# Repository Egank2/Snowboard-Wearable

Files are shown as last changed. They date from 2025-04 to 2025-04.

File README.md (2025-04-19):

# 🏂 Snowboard Wearable – IoT-Based Ride Tracker

Welcome to the Snowboard Wearable project repository! This system is designed to help snowboarders visualize, analyze, and improve their performance using a wearable IoT device and a companion mobile application. It combines real-time sensor data, Bluetooth connectivity, trick recognition, and a gamified mobile UI for a next-generation snowboarding experience.

---

## 📱 Mobile App Features

- 🌤 **Weather & Conditions Dashboard** (Live resort data)
- 🏔 **Popular Resorts** listing with status
- 🔋 **Equipment Status Monitor** (Device, goggles, bindings)
- 🏆 **Leaderboards** (Daily, Weekly, Monthly, All-Time)
- 📊 **Trick Analytics** (Top speed, airtime, spins)
- 🕹 **3D Playback** of runs with XP scoring
- 👤 **User Profile & Stats** (XP, badges, levels)

Built using **Flutter**, supports Android 10+ and iOS 14+.

---

## ⚙️ Hardware Features

- 🎯 **ESP32-WROVER Module** for BLE and onboard control
- 🧭 **BNO086 IMU Sensor** for 9-axis motion tracking
- 🔌 **USB-C Charging** with Li-ion battery management
- 📉 **Low-Dropout Regulator (LDO)** for power efficiency
- 🧩 Designed and simulated in **KiCad 7.0**

---

## 🧪 Current Development Status

| Component | Status |
|---|---|
| Mobile UI | ✅ In Progress |
| ESP32 Firmware | ✅ Completed |
| IMU Integration | ✅ Completed |
| Trick Recognition ML | ✅ In Progress |
| Cloud Sync & Storage | 🔄 Planned |
| Hardware Prototype | ✅ Assembled |
| Full Integration | ❌ Not Completed |

---

## 🔧 Getting Started

### 📱 Mobile App (Swift)

### ⚡ Firmware (ESP32)

- Board: `ESP32-WROVER-E`
- Upload via USB using PlatformIO or Arduino IDE
- Ensure I²C is connected to the IMU (BNO086) with proper pull-ups

## 🧑‍💻 Team 06 — WIT COMP4960

- Emerson Herrera  
- Kenneth Egan
- Aakash Mukherjee 
- David Kennet  
- Victor Lomba  
Instructor: Dr. Joshua Gyllinsky

---

## 📘 Documentation

- [📄 SRS – Software Requirements Spec](Documents/SRS(Version%201.5).pdf)
- [📄 SDD – Software Design Document](Documents/SDD(Version%201.4).pdf)

---

## 🤝 Contributions

Pull requests are welcome! For major changes, please open an issue first to discuss what you'd like to change.  
Please follow our [Code of Conduct](docs/CODE_OF_CONDUCT.md).

---

## 📜 License

This project is intended for academic and research use only.
All rights reserved. Unauthorized use, reproduction, or distribution is prohibited.

---

## 🏔️ Let's Ride.

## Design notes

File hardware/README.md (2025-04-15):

# Hardware
## Overview
### electrical
KiCad9 project files. Contains PCB layout and schematic.
### models
3D CAD models of the housing. Contains the cover and bottom housing models.
### software
Software that runs in the microcontroller on the PCB.

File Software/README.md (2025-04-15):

# Software
## Overview
### max_velocity.py
Script that finds the maximum velocity of a run.
### plotter.py
Connects to a snowboard device through Bluetooth. Visualizes in 3D and logs to a file.
### snowboard_wearable.py
Detects snowboarding techniques and plots the result.
### test_bt.py
Bluetooth test script.
### trick_recognition.py
Detects tricks in a run.
## Setup
### Install python requirements
```
$ pip install -r requirements.txt
```
## Usage
### Running any of the scripts
```
$ python [script name]
```

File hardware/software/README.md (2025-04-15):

# software
## Overview
### snowtrack
ESP-IDF project that was supposed to run on the ESP32. After having issues with the newer v5.5.0 I2C driver along with time constraints due to ski resort availability, we decided to abandon this project.

The reason for the issues stems from the BNO08x requiring that the host device has SCL clock stretching enabled. However, the ESP32 I2C driver does not have SCL stretch capability. This was realized after committing to using a ESP32-WROVER and I2C. If I were to do this again I would redesign the board to use SPI instead.
### snowtrack-proto
Simple arduino program that sends the current rotation of the BNO086 to a host through Bluetooth.

This is what was used to record all of the snowboarding runs.

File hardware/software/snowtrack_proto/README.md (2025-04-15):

# snowtrack_proto
## Build & Flash
1. Install esp32 in the Arduino IDE board manager.
2. Select ESP32 Wrover Module in the board selection.
3. Have ESP32 connected and press Upload.
4. The device should show up as 'SnowTrack'

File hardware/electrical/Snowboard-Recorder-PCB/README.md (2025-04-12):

# Snowboard-Recorder-PCB
Snowboard performance tracking PCB.

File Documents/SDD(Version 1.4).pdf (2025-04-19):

# Snowboarding Wearable SDD

WIT COMP4960 Group 06
Version 1.4
Instructor: Dr. Joshua Gyllinsky https://github.com/Egank2/Snowboard-Wearable.git

Emerson Herrera, Aakash Mukherjee, Kenneth Egan, David Kennet, Victor Lomba

April 14, 2025

## Contents

1 Introduction | 2
2 System Requirements | 3
3 System Architecture | 4
4 System Design | 6
5 Hardware Architecture & Electrical Design | 9
6 Mobile Application UI Design | 11
7 Test Plan | 15
8 References | 15
9 Conclusion & Status Summary | 15

## Revision History

Date | Version | Description | Author(s)
Mar 19, 2025 | 1 | First Draft | Group 6
Apr 14, 2025 | 2 | Final Draft | Group 6

## 1 Introduction

### 1.1 Document Purpose

This document provides a comprehensive software design for the Snowboarding Wearable project. It details the architecture, system components, and design decisions that satisfy the system requirements defined in the SRS. The purpose is to serve as a guide for implementation and future maintenance while ensuring alignment with user needs and technical constraints.

### 1.2 Product Overview

The Snowboarding Wearable is a wearable IoT device for snowboarders that attaches to the board and connects to a phone via Bluetooth. It collects data from sensors like a gyroscope, accelerometer, GPS, and altimeter, providing post-ride analysis such as speed, airtime, technique analysis, and trick recognition. It can analyze snowboard-specific dynamics like carving angles, board flex, and snow conditions. Ride visualization, performance grading, and tips to help riders improve and tailor their experience to different terrains, making it an essential tool for snowboarders of all levels.

1.2.1 Problem Statement: Snowboarders lack a dedicated tool for analyzing ride performance and improving techniques.

1.2.2 Proposed Solution: A wearable IoT device coupled with a mobile app that provides real-time feedback and post-ride analytics.

1.2.3 Novelty: Focus on snowboard-specific dynamics (carving angles, edge angles, posture) with advanced trick recognition and performance grading.

### 1.3 Product Functionality

1.3.1 Real-Time Data Collection: Continuously capture sensor data (gyroscope, accelerometer, GPS, altimeter).

1.3.2 Trick Recognition: Identify snowboard tricks using predefined movement signatures.

1.3.3 Performance Grading: Analyze parameters such as carving efficiency, airtime, and landing stability.

1.3.4 Data Visualization: Present 3D ride visualizations and detailed performance graphs on the mobile app.

1.3.5 Historical Data Analytics: Store ride history for long-term progress tracking.

1.3.6 Wireless Communication: Ensure seamless Bluetooth connectivity between the wearable and mobile app.

### 1.4 Definitions

1.4.1 IoT: Internet of Things

1.4.2 BLE: Bluetooth Low Energy

1.4.3 GPS: Global Positioning System

1.4.4 ESP32: A low-power microcontroller with integrated Bluetooth/Wi-Fi

1.4.5 IMU: Inertial Measurement Unit (e.g BNO086)

### 1.5 Acronyms and Abbreviations

1.5.1 SDD: Software Design Document

1.5.2 SRS: Software Requirements Specification

1.5.3 UI: User Interface

1.5.4 API: Application Programming Interface

1.5.5 MVC: Model-View-Controller

1.5.6 PCB: Printed Circuit Board

## 2 System Requirements

### 2.1 Functional Requirements

Based on the SRS and architectural design, the system must:

2.1.1 Bluetooth Connectivity: Enable a stable Bluetooth connection between the wearable device and the mobile app.

2.1.2 Sensor Data Collection: Gather data from gyroscope, accelerometer, GPS, and altimeter sensors at a sampling rate of 200Hz.

2.1.3 Trick Recognition: Process movement data using machine learning algorithms to identify and score tricks.

2.1.4 Real-Time Performance Grading: Provide immediate feedback on ride metrics such as carving angles and landing stability.

2.1.5 User Interface for Data Visualization: Display real-time and historical ride data through an intuitive mobile app interface.

2.1.6 Cloud Integration: Support data storage and long-term trend analysis.

### 2.2 Non-functional Requirements

2.2.1 Performance:

- Data transmission latency ≤ 50ms.
- Sensor sampling rate of 200Hz.

2.2.2 Reliability: Device must function in extreme cold (as low as –20°C) and snowy conditions.

2.2.3 Battery Life: Minimum operational time of 4–8 hours per charge.

2.2.4 Packaging: Compact and durable design, ensuring minimal interference with rider movement.

2.2.5 Security: Encrypted Bluetooth data transmission and secure data storage.

2.2.6 Platform Compatibility: Mobile app to support Android 10+ and iOS 14+.

## 3 System Architecture

### 3.1 Overall Architecture

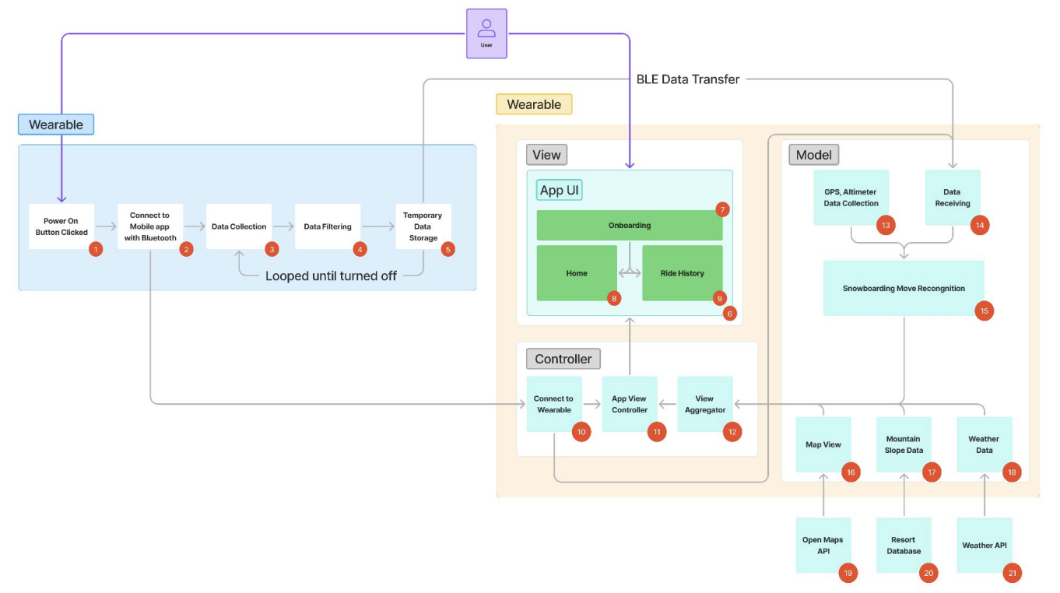
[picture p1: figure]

The system follows a combination of a Client-Server model, an MVC and a pipe and filter consisting of two primary components:

IoT Wearable (Client): Utilizes a Pipe & Filter pattern to collect and pre-process sensor data. The core hardware includes an ESP32 for Bluetooth communication and sensors (e.g., BNO086) for motion tracking.

Mobile App (Server): Implements a Model-View-Controller (MVC) design to ensure a clear separation between the user interface, data processing (using TensorFlow Lite for trick recognition), and control logic. The app manages data visualization, performance grading, and cloud integration.

### 3.2 Components Mapping

The functional and non-functional requirements are mapped to specific system components as follows:

Functional Requirements Mapping

3.2.1.1 Bluetooth Connectivity: (2, 10) Handled by the ESP32 and Flutter Blue library on the mobile app.

3.2.1.2 Sensor Data Collection: (1, 2, 3, 4, 5, 13) Managed by the wearable’s sensor module and data filtering algorithms.

3.2.1.3 Trick Recognition: (13, 14, 15) Executed on the mobile app using TensorFlow Lite along with predefined movement signatures.

3.2.1.4 Performance Grading: (13, 14, 15) Integrated within the mobile app’s analytics module.

3.2.1.5 Data Visualization: (15, 17, 12, 11, 6) Provided by the mobile app’s UI components, including 3D ride visualization.

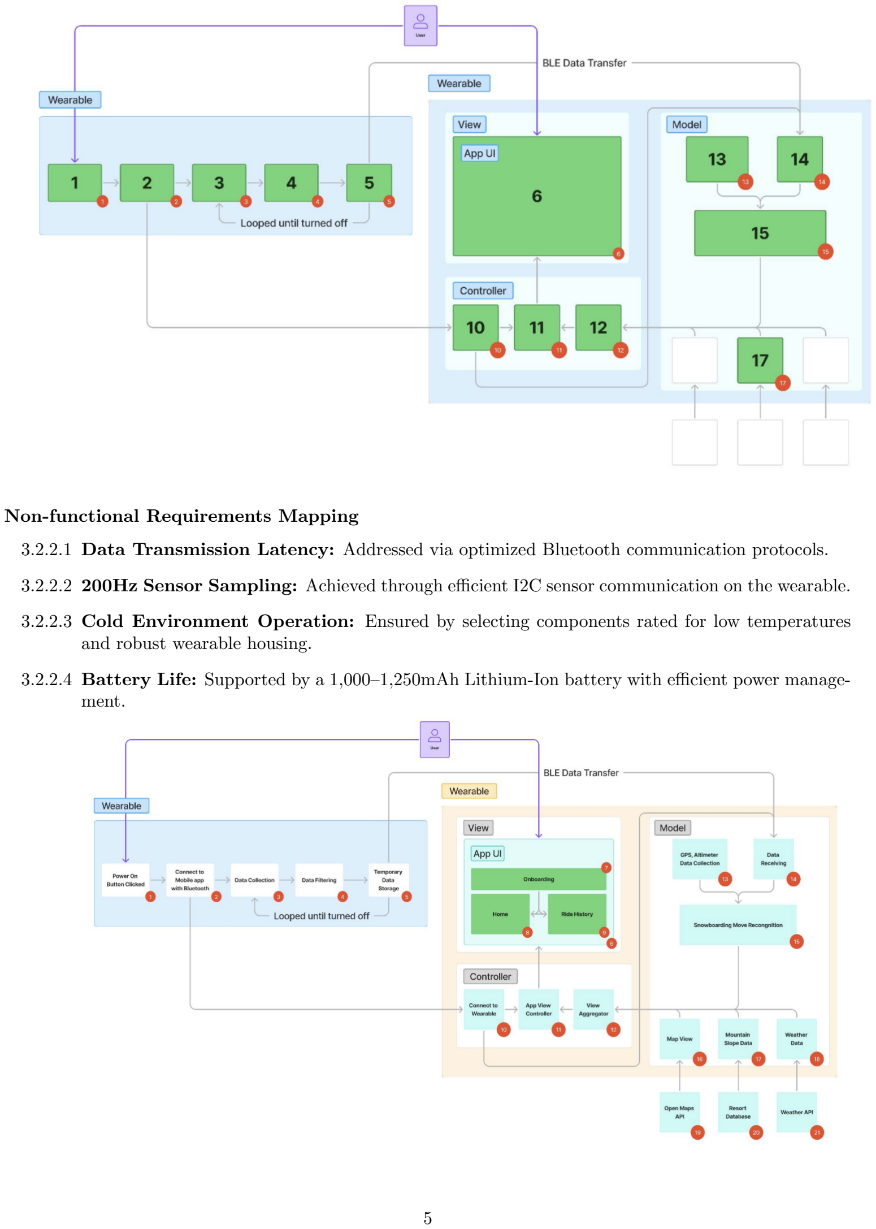
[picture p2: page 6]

Non-functional Requirements Mapping

3.2.2.1 Data Transmission Latency: Addressed via optimized Bluetooth communication protocols.

3.2.2.2 200Hz Sensor Sampling: Achieved through efficient I2C sensor communication on the wearable.

3.2.2.3 Cold Environment Operation: Ensured by selecting components rated for low temperatures and robust wearable housing.

3.2.2.4 Battery Life: Supported by a 1,000–1,250mAh Lithium-Ion battery with efficient power management.

### 3.3 Technology Stack Selection

3.3.1 Mobile App:

3.3.1.1 Flutter: For cross-platform UI development.
3.3.1.2 Flutter Blue: To manage Bluetooth Low Energy (BLE) communication.

3.3.1.3 TensorFlow Lite: For executing on-device machine learning models for trick recognition.

3.3.2 APIs:

3.3.2.1 Open Maps API: To fetch slope and mapping data.

3.3.2.2 Weather API: To deliver real-time snow and weather conditions.

3.3.3 Wearable Hardware:

3.3.3.1 ESP32: For Bluetooth and onboard processing.

3.3.3.2 Sensors: BNO086 for motion and orientation data.

3.3.3.3 Battery Pack: 3.7V, 1,000–1,250mAh Lithium-Ion battery ensuring power efficiency in cold climates.
3.3.3.4 Enclosure: IP67/IP68-rated housing for durability.

## 4 System Design

### 4.1 User Interface (UI)

The mobile app UI is designed with the following screens:

– Splash Screen: Displays the app logo for 3–5 seconds upon launch.

– Onboarding Screen: Guides first-time users through device pairing and setup.

– Home Screen:

- Real-time 3D visualization of snowboard movements.
- Map view displaying current ride path and GPS tracking.
- Performance scoring and feedback section.

– History Log Page:

- List of previous rides with metadata (date, time, score, etc.).
- Detailed view for individual ride analytics with graphs and 3D replay.

– Navigation Bar: Persistent access to key sections of the app.

### 4.2 Use Case Diagrams and Tables

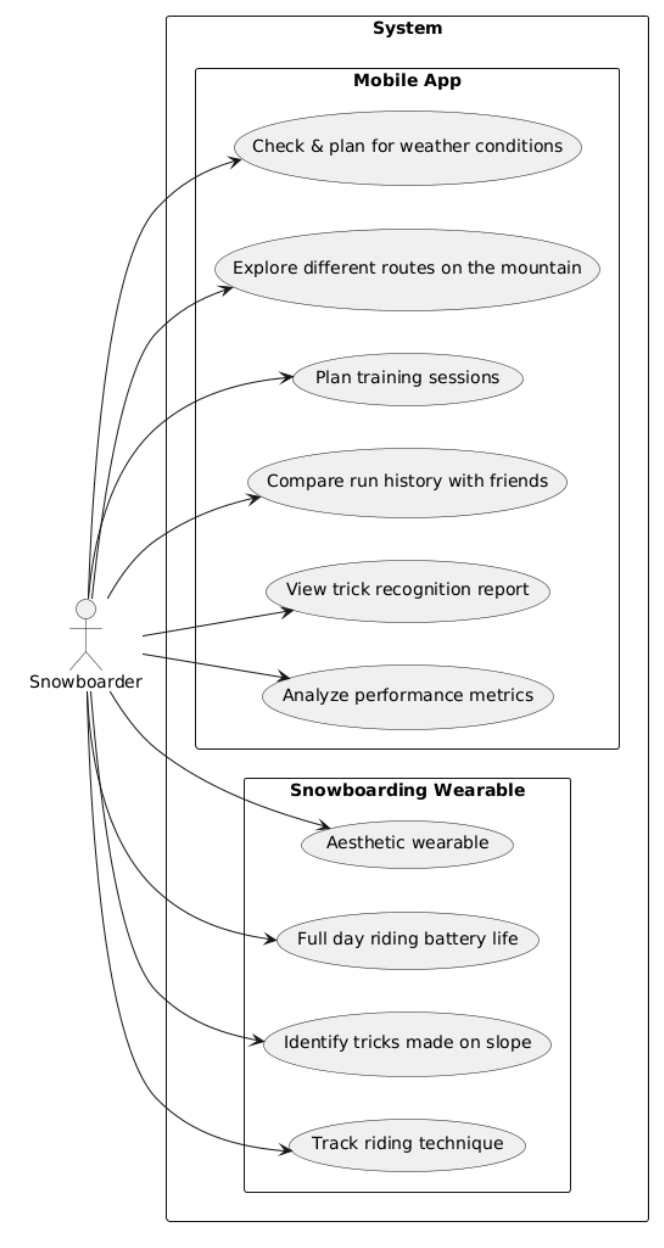
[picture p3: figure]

– Device Pairing:

- Actors: User, Wearable Device, Mobile App.
- Description: The user initiates Bluetooth pairing; the mobile app establishes a connection and confirms device readiness.

– Real-Time Data Visualization:

- Actors: User, Mobile App.
- Description: Sensor data is received and processed, then visualized on the home screen.

– Trick Recognition and Feedback:

- Actors: User, Mobile App.
- Description: The mobile app analyzes sensor inputs, recognizes tricks, and provides performance grading.

Detailed use case tables are maintained in the project repository.

### 4.3 Class Diagram

The class diagram includes (but is not limited to) the following classes:

– MobileApp:

- Attributes: userProfile, rideHistory, currentSession.
- Methods: displayUI(), initiatePairing(), updateData().

– BluetoothManager:

- Attributes: connectionStatus, deviceList.
- Methods: connect(), disconnect(), sendData(), receiveData().

– SensorDataManager:

- Attributes: sensorReadings, filteredData.
- Methods: collectData(), filterNoise(), triggerTrickRecognition().

– TrickRecognitionEngine:

- Attributes: model, trickDatabase.
- Methods: analyzeData(), classifyTrick(), provideFeedback().

– DataAnalyticsModule:

- Attributes: performanceMetrics, historicalData.
- Methods: calculateScore(), generateReports(), updateHistory().

### 4.4 Sequence/Activity Diagram

Device Pairing and Data Transmission Sequence:

1. User Action: Launch mobile app and initiate pairing.
2. BluetoothManager: Scans for the wearable and establishes a connection.
3. SensorDataManager (Wearable): Begins collecting and filtering sensor data.
4. Data Transfer: Processed sensor data is transmitted to the mobile app with latency ≤ 50ms.

5. TrickRecognitionEngine: Receives data, analyzes movement patterns, and classifies tricks.
6. DataAnalyticsModule: Computes performance grading and updates the UI.
7. UI Update: Mobile app displays real-time analytics and visualizations.

Detailed activity diagrams are maintained as supplementary design files.

### 4.5 Database Design

Cloud Storage: Stores historical ride data including sensor readings, performance scores, and user profiles.

Local Database (on Mobile App):

– Tables:

- Rides: rideID, dateTime, score, GPS data.
- UserProfile: userID, name, preferences.
- SensorData: sensorID, rideID, dataPoints.

– Data Model: Uses a relational schema ensuring data integrity and efficient querying.

## 5 Hardware Architecture & Electrical Design

The Snowboard Wearable device is built around a compact, low-power embedded system designed for extreme cold weather conditions and real-time sensor data acquisition. The electrical design was implemented using KiCad 7.0. It includes a full schematic diagram, PCB layout, and 3D board rendering to validate component placement and mechanical fit.

### 5.1 Overview

The hardware system integrates:

- ESP32-WROVER Module (U1): Central microcontroller responsible for Bluetooth communication and control logic. It operates at 3.3V and interfaces with sensors and the mobile application.
- IMU Sensor – BNO086 (U5): Provides 9-axis motion tracking via I²C for trick recognition and ride analysis.
- Battery Management Circuit (U4): Uses an MCP73831T-2ACI/OT Li-ion charger IC for regulated charging via the USB port.
- Power Supply Circuit (U3): Converts 5V input to 3.3V using the SPX3819 LDO regulator to power the ESP32 and sensors.
- USB–UART Bridge (U2): CP2102N for serial communication and flashing firmware over USB.
- Boot and Reset Buttons (SW1, SW2): Manual control for entering programming mode and restarting the ESP32.

### 5.2 Schematic Design

The schematic includes carefully designed protection and power management:

- Schottky diode (MBR120) to prevent reverse current flow from battery to USB.
- Test points for debugging critical pins (e.g., I²C lines, RX/TX, EN, BOOT).
- Pull-up/down resistors for proper GPIO initialization.

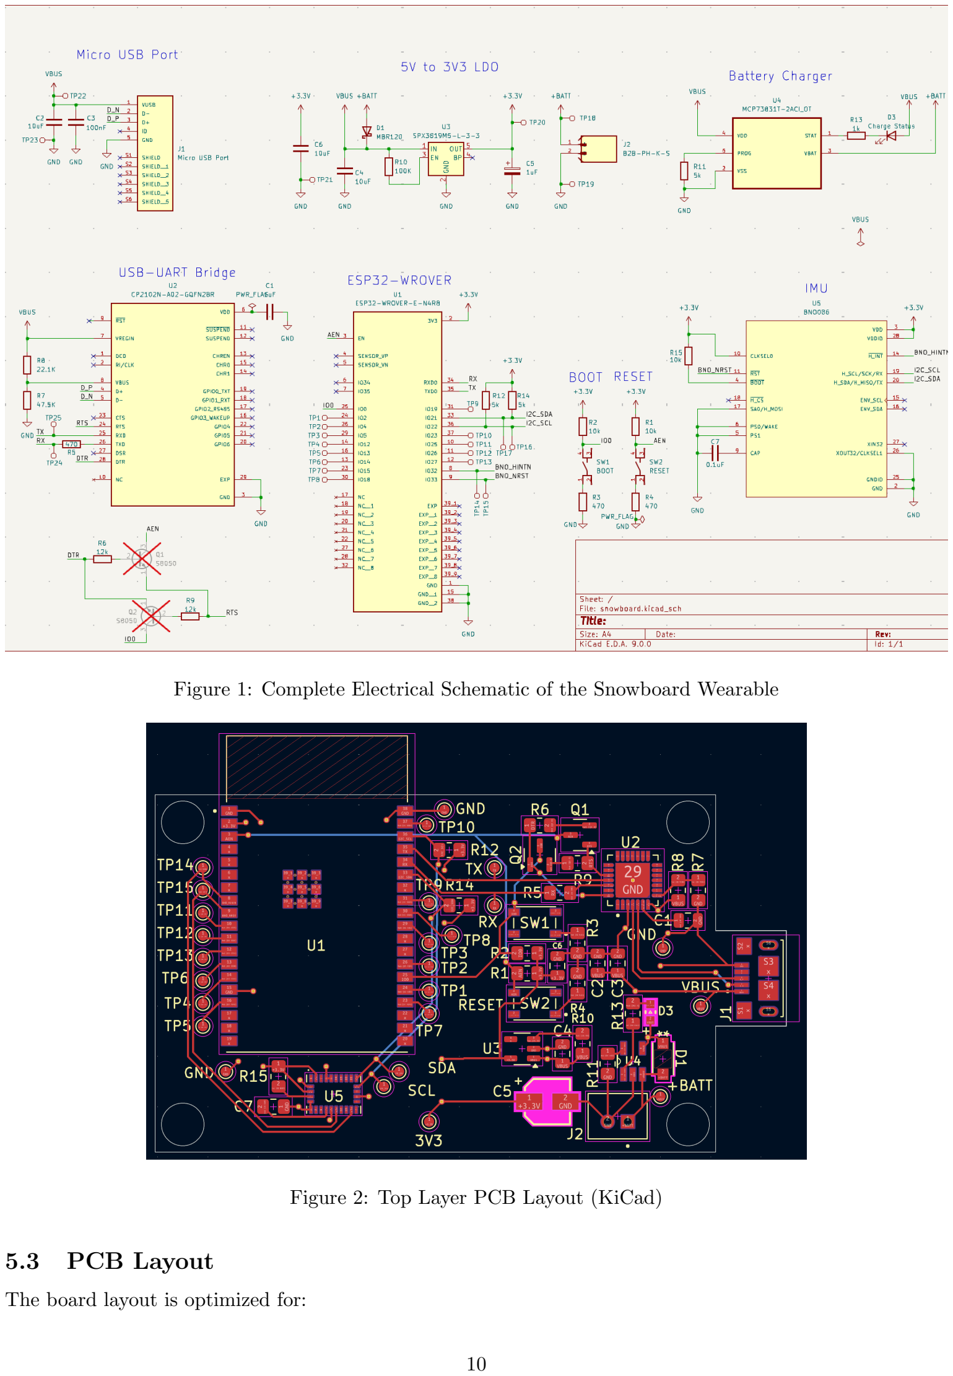
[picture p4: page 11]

Figure 1: Complete Electrical Schematic of the Snowboard Wearable

Figure 2: Top Layer PCB Layout (KiCad)

### 5.3 PCB Layout

The board layout is optimized for:

- Compact size with mounting holes at all four corners.
- Minimized trace length for I²C communication to reduce noise.
- Clearly labeled test points and headers for rapid prototyping and field debugging.
- Ground plane continuity and proper decoupling capacitor placement for noise reduction.

5.4 3D Model

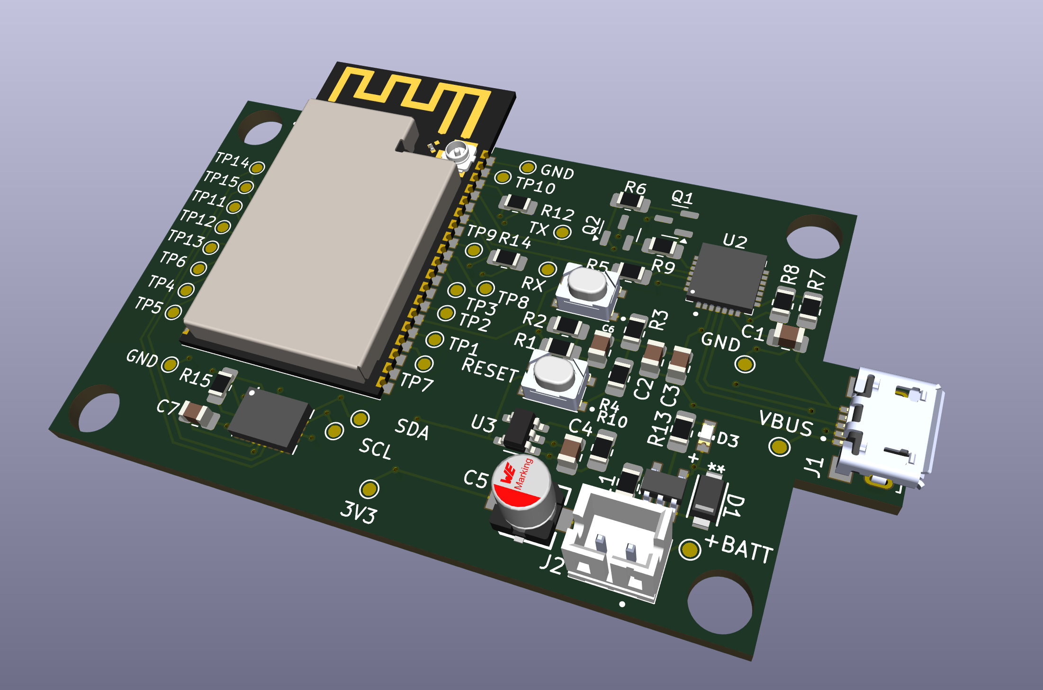
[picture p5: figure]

Figure 3: 3D PCB Rendering

The 3D rendering validates:
- Mechanical alignment of USB port, battery connector, and push buttons.
- Proper spacing for the ESP32 module antenna for optimal wireless performance.
- Component placement consistency with electrical and thermal design rules.

### 5.5 Design Considerations

- The board supports cold-weather operation (−20◦C) with components rated for low temperatures.
- LDO regulator and power rail design minimizes power loss, supporting up to 5 hours of continuous use.
- IP68-compatible mechanical design under consideration for final enclosure integration.

This hardware implementation represents the foundation for the wearable system’s real-time data acquisition capabilities and seamless mobile integration. The design files are maintained in the project repository for future enhancements and manufacturing.

## 6 Mobile Application UI Design

The mobile application for the Snowboarding Wearable device serves as the primary interface for users to interact with their ride data, track progress, and receive feedback. Designed in Flutter, the UI focuses on clarity, accessibility, and gamified engagement. Below is an overview of the four main screens currently designed and implemented.

### 6.1 Home Screen

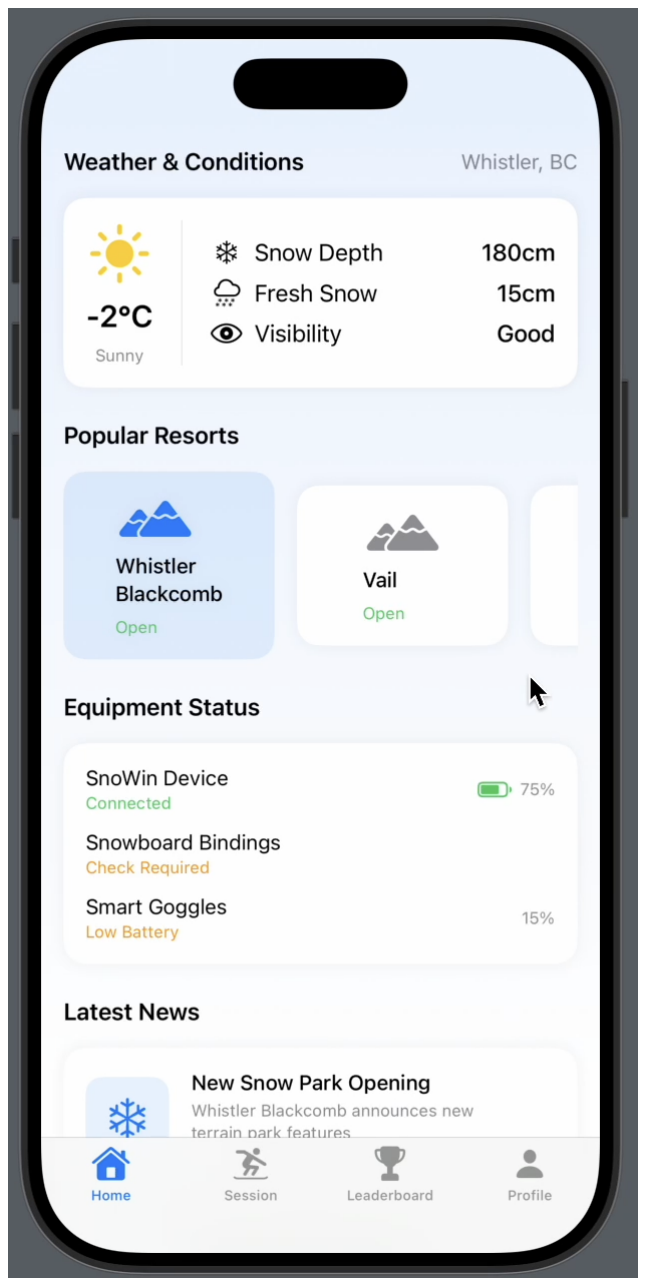
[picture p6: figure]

Figure 4: Home Screen — Real-Time Weather and Device Status

The home screen delivers high-level contextual and environmental data to prepare users for snowboarding sessions:

- Weather Conditions: Real-time weather, snow depth, fresh snow, and visibility at the selected resort (e.g., Whistler).
- Popular Resorts: A horizontal scroll of available resorts and their current status (Open/Closed).
- Equipment Status: Displays the connectivity and battery levels of key gear including the SnowWin device, snowboard bindings, and smart goggles.
- Latest News: Dynamic content on resort announcements and feature rollouts.

### 6.2 Leaderboard Screen

The leaderboard integrates social competition to drive user engagement and improvement:

- Top Performers: Ranks weekly, daily, monthly, and all-time snowboarders based on experience points (XP).
- Category Highlights: Highlights the top user in key metrics such as highest jump, top speed, and most tricks.
- Friends Ranking: A personalized leaderboard comparing XP with friends.

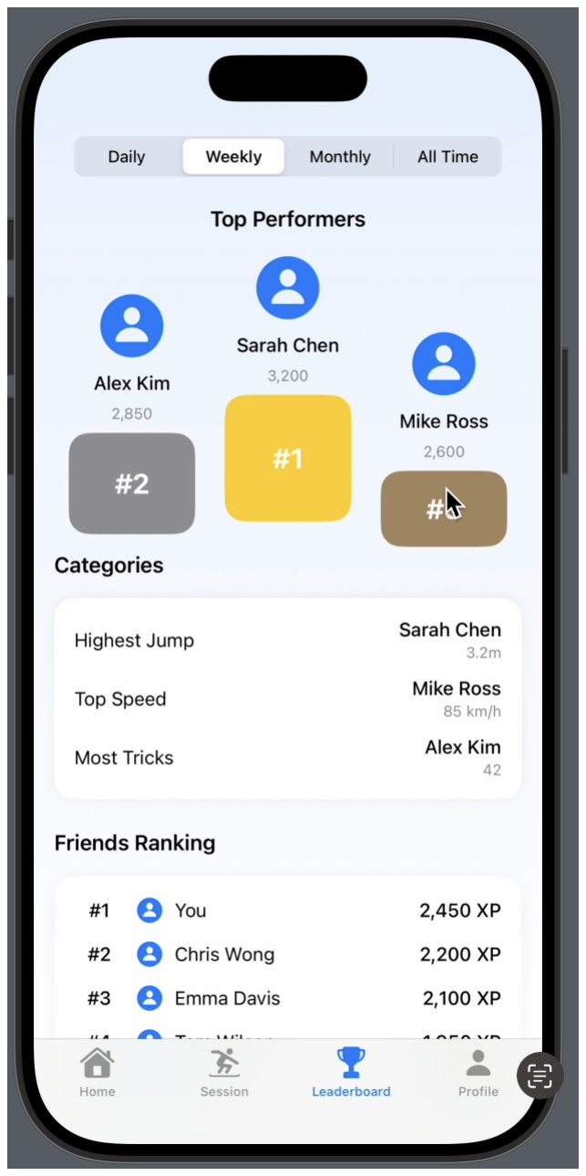
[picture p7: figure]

Figure 5: Leaderboard Screen — Gamification and Social Ranking

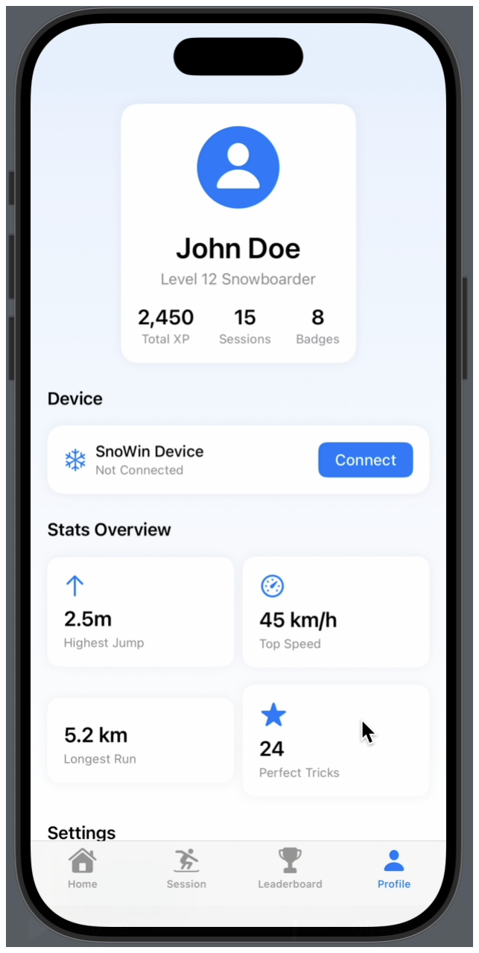
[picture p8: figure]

Figure 6: Profile Screen — User Summary and Stats Overview

### 6.3 Profile Screen

The profile screen helps users track their long-term progress and device connectivity:

- User Identity: Name, XP level, number of sessions, and earned badges.
- Device Status: Allows users to connect/disconnect their SnowWin device.
- Stats Overview: Summarizes personal performance metrics: highest jump, top speed, longest run, and perfect tricks.

### 6.4 Session Playback Screen

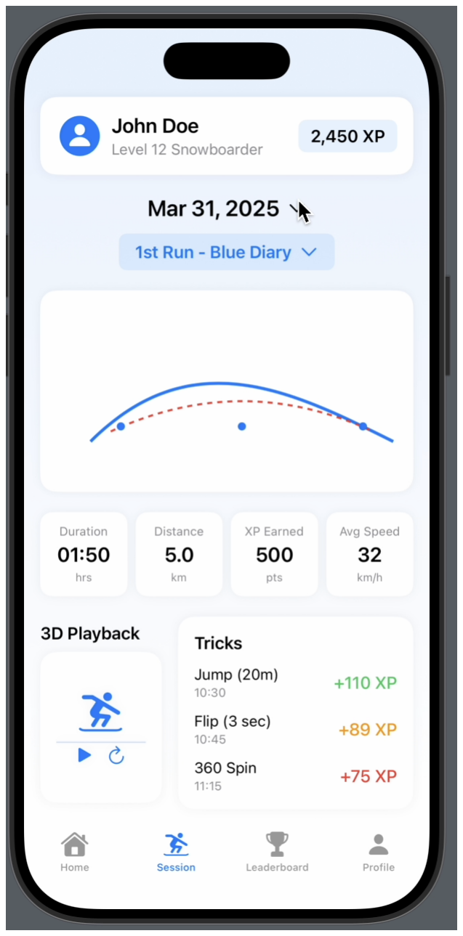
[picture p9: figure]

Figure 7: Session Screen — Performance Analytics for Each Run

This screen provides post-session analysis, breaking down an individual snowboarding session:

- Run Summary: Displays XP earned, ride duration, average speed, and distance.
- 3D Playback: Preview of trajectory and motion using real-time sensor data.
- Trick List: Timestamped list of recognized tricks, XP earned per trick, and execution quality.

### 6.5 Design Considerations

- The UI follows a bottom-tab navigation structure for seamless access to Home, Session, Leaderboard, and Profile sections.
- A gamified XP system and leaderboard foster engagement and motivation for skill improvement.
- UI components are designed with accessibility, clarity, and winter-sport usability in mind — including large tap targets and legible fonts.

The current interface is optimized for iOS 14+ and Android 10+ devices and will continue to evolve as new features are implemented and user testing insights are gathered.

## 7 Test Plan

### 7.1 Test Plan Overview

Testing is structured around verifying both functional and non-functional requirements. The table below outlines the key test cases:

No. | Test Case Description | User Input/Action | Pass Criteria
1 | Device Pairing | User initiates pairing via mobile app | Successful Bluetooth con-nection with the wearable established
2 | Sensor Data Transmission | Wearable sends sensor data con-tinuously | Data received with la-tency ≤ 50ms; sensor sam-pling at 100Hz
3 | Trick Recognition Accuracy | Perform known trick maneuvers | System correctly identifies and scores the trick with > 70% accuracy
4 | UI Data Visualization | User navigates to home screen | 3D ride visualization and performance data are ac-curately displayed
5 | Battery Life Test | Continuous operation over 5 hours | Device maintains opera-tion for minimum required duration

## 8 References

– Architectural Design Presentation – Group 6, COMP4960 – Software Engineering, Feb. 18, 2025.

– SRS Document – WIT COMP4960 SP25 Group06 (Version 1.2, January 2025).

– SDD Sample Document – Wentworth Institute of Technology Format.

Additional references:

- Espressif ESP32 Datasheet
- Ceva BNO08X Datasheet
- OpenStreetMap License
- Open-Meteo License
- Flutter and Flutter Blue documentation

## 9 Conclusion & Status Summary

This Software Design Document outlines the architecture, component design, and system functionality for the Snowboarding Wearable project, aimed at delivering a data-driven performance analysis tool for snowboarders. It documents all major design decisions, technology choices, and the system’s modular breakdown across hardware, mobile software, and analytics.
As of April 14, 2025, the project has completed key phases including:

- A functional design of the mobile app UI with data visualization components.
- Configuration and partial testing of the wearable hardware system using the ESP32 and BNO086 IMU.
- Development of a modular software architecture accommodating sensor integration, Bluetooth communication, and analytics pipelines.
- Semi-functional simple trick recognition with decent accuracy

However, full system integration—specifically the real-time connection between the mobile application, the hardware device, and the trick recognition algorithm remain incomplete. A few simple trick recognition algorithms were able to be programmed, however more advanced learning-based trick recognition features could not be implemented within the current project timeline and is marked for future development. Despite these limitations, the current version still lays a solid technical foundation for further iterations. Future work should focus on completing the hardware-software integration, training and embedding the trick recognition model, and performing field testing to refine user experience and system performance.
This document serves as a comprehensive guide for future teams or contributors who wish to continue or expand upon this project.

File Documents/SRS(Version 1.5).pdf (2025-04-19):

# Snowboard Wearable

WIT COMP4960 Group 06 SRS
Version 1.5

Aakash Mukherjee, Victor Lomba, Emerson Herrera, Kenneth Egan, David Kennet

April 14, 2025

## Document History

The following table provides a version history of the Software Requirements
Specification (SRS) for the Snowboard Wearable project.
Version | Submitted / Ap-proved By | Date | Changes Made | Associated Documents
1.0 | Kenny Egan | Mar 4, 2025 | Initial draft re-lease | Project Proposal
1.2 | Kenny Egan | Mar 25, 2025 | Added interface requirements | Weekly Team Re-port 3
1.3 | Kenny Egan | Apr 5, 2025 | Revised sensor details, replaced MPU6050 with BNO086 | Hardware BOM v2
1.4 | Kenny Egan | Apr 14, 2025 | Finalized v1 features; added feature sum-mary section | Version 1.4 SDD
1.5 | Kenny Egan | Apr 20, 2025 | Added Docu-ment History & Removed Requirements Table | Version 1.5 SDD, SRS Update

Table 1: Document History of the SRS

## Contents

1 Introduction | 2
2 Introduction | 2
3 Overall Description | 4

1

4 Specific Requirements | 5
5 Feature Summary & Development Status | 8

## 1 Introduction

### 1.1 Purpose

A wearable Internet-of-Things (IoT) device for snowboarders that attaches to the board and connects to a phone via Bluetooth. It collects data from sensors like a gyroscope, accelerometer, GPS, and altimeter, providing post-ride analysis such as speed, airtime, technique analysis, and trick recognition. It can analyze snowboard-specific dynamics like carving angles, board flex, and snow conditions. Ride visualization, performance grading, and tips to help riders improve and tailor their experience to different terrains, making it an essential tool for snowboarders of all levels.

## Contents

## 2 Introduction

### 2.1 Purpose

A wearable Internet-of-Things (IoT) device for snowboarders that attaches to the board and connects to a phone via Bluetooth. It collects data from sensors like a gyroscope, accelerometer, GPS, and altimeter, providing post-ride analysis such as speed, airtime, technique analysis, and trick recognition. It can analyze snowboard-specific dynamics like carving angles, board flex, and snow conditions. Ride visualization, performance grading, and tips to help riders improve and tailor their experience to different terrains, making it an essential tool for snowboarders of all levels.

2

### 2.2 Scope

The Snowboarding Wearable is a smart IoT device that attaches to a snowboard and communicates wirelessly through Bluetooth, with a mobile application. The key features of the system include:

1.2.1 Data collection from IMU, and GPS.

1.2.2 Performance grading, providing feedback on carving angles, and snow conditions.

1.2.3 Ride visualization for post-ride analysis.

1.2.4 Recommendations based on user riding style and skill level.

Note: As of this submission, the following features have not yet been implemented but are still planned for future development: performance grading, ride visualization, mobile app, and recommendations. These features will be developed after the deadline.

### 2.3 Definitions

1.3.1 IoT: Internet of Things.

1.3.2 GPS: Global Positioning System

1.3.3 ESP32: Espressif Systems 32 Microcontroller SoC

1.3.4 BNO086: 9-axis IMU

1.3.5 API: Application Programming Interface

1.3.6 BLE: Bluetooth Low Energy

### 2.4 Pertinent Resources

1.4.1 IEEE 830-1998: Recommended Practice for Software Requirements Specifications

1.4.2

[1] B. H. Groh, M. Fleckenstein, and B. M. Eskofier, “Wearable trick classification in freestyle snowboarding,” in Proc. IEEE Conf., 2016.

1.4.3 ”Carv” - A similar product for skiing

3

## 3 Overall Description

### 3.1 Product Perspective

The Snowboarding Wearable is a standalone hardware device with embedded sensors that include a gyroscope, accelerometer, and magnetometer, which transmit data wirelessly to a mobile application. The mobile application provides the user interface for data visualization, performance insights, and suggestions. The system is designed to operate in cold conditions with minimal power consumption.

### 3.2 Product Functions

2.2.1 Data Capture: Continuous monitoring of motion and environmental variables.

2.2.2 Sensor Fusion Processing: Combining data from gyroscope, accelerometer, magnetomeer, and GPS, for accurate motion tracking.

2.2.3 Trick Recognition: Classifies tricks based on motion signatures.

2.2.4 User Performance Grading: Scores rides based on various parameters such as airtime, and carving efficiency.

2.2.5 Historical Data Analytics: Stores ride history and tracks long-term improvement trends.

### 3.3 User Characteristics

2.3.1 Beginner Snowboarders: Need guidance and feedback to improve basic riding techniques.

2.3.2 Intermediate Riders: Seek analytics on tricks and advanced performance improvement.

2.3.3 Professional Athletes: Require precision metrics and detailed analysis of tricks and competition preparation.

### 3.4 Constraints

2.4.1 Environmental Conditions: The wearable must function in extreme cold (as low as -20°C) and withstand exposure to snow and moisture.

2.4.2 Power Efficiency: The device must operate for a minimum of 5 hours on a single charge despite the high-energy demands of sensors and wireless communication.

2.4.3 Bluetooth Connectivity Range: The wearable must maintain a stable connection to the mobile app within a 5-meter range, which may be affected by environmental interference.

4

2.4.4 Data Transmission: The system must process and transmit data, while ensuring minimal delay in user feedback.

2.4.5 Testing Challenges: Due to the requirement for real-world testing on slopes, a simulated physics-based environment in a game engine will be needed for preliminary testing.

### 3.5 Assumptions and Dependencies

2.5.1 The wearable will be compatible with iOS and Android.

2.5.2 GPS signal must be available in riding areas for accurate location tracking.

## 4 Specific Requirements

### 4.1 External Interface Requirements

### 4.1.1 Mobile App (Client-Side User Interface)

3.1.1.1 Splash Screen: A basic screen displaying the logo to welcome the user for 3-5 seconds.

3.1.1.2 Onboarding Screen: A step-by-step guide to help the user connect the phone to the wearable.

3.1.1.2.1 Displayed only when the device is not already connected. 3.1.1.2.2 Not manually accessible by the user.

3.1.1.3 Home Screen: Displays data from the most recent run.

3.1.1.3.1 Map view of the slope with GPS-based movement tracking. 3.1.1.3.2 Scoring section displaying user performance based on number and quality of runs.
3.1.1.3.3 List of recommended improvements/tips based on collected data.
3.1.1.3.4 Clicking on a suggestion leads to a page with graphical/3D visualization of raw data. 3.1.1.3.5 A navigation bar at the bottom for easy access to other sections.

3.1.1.4 History Log Page:

3.1.1.4.1 Displays a list of past runs recorded when the device was active.
3.1.1.4.2 Allows users to select specific runs for detailed analysis. 3.1.1.4.3 Each entry contains metadata such as date, time, location, and total score.
3.1.1.4.4 Includes a navigation bar at the bottom for easy access.

5

### 4.1.2 Mobile App (Backend)

3.1.2.1 Establishes and maintains a continuous Bluetooth connection with the wearable.

3.1.2.2 Receives data from the device with a latency of 100ms.

3.1.2.3 Implements algorithms to combine sensor data for analyzing snowboard movement.

3.1.2.4 Processes and displays collected data in the user interface.

### 4.1.3 Hardware Wearable (IoT Device)

3.1.3.1 Core Components:

3.1.3.1.1 ESP32 Dev Board for Bluetooth communication and onboard processing.

3.1.3.1.2 BNO086 9-axis IMU for capturing acceleration, rotational velocity, and orientation data. Selected for its robust sensor fusion capabilities and motion detection accuracy. 3.1.3.1.3 Battery Pack (3.7V, 1000mAh) supporting at least 4 hours of continuous operation at temperatures as low as -20°C.

3.1.3.2 Durability:

3.1.3.2.1 IP68-rated waterproof and shockproof casing for protection in extreme snow conditions.

3.1.3.2.2 Clip-on attachment for securing the device to the snowboard boot.

3.1.3.2.3 Physical button on the outer casing for power control.

3.1.3.3 Charging Mechanism:

3.1.3.3.1 USB-C breakout board for charging.

3.1.3.3.2 Optional low-dropout voltage regulator to ensure stable power delivery.

### 4.2 Objects

### 4.2.1 Sensor Data Collection and Storage

3.2.1.1 Attributes:

3.2.1.1.1 Gyroscope Data: Measures rotation and angular velocity.

3.2.1.1.2 Accelerometer Data: Tracks acceleration changes across multiple axes.

6

3.2.1.1.3 GPS Coordinates: Determines location and speed, leveraging phone GPS data.

3.2.1.2 Functions:

3.2.1.2.1 Capture and store sensor readings.

3.2.1.2.2 Apply filtering and normalization to raw data.

3.2.1.2.3 Send processed data to the mobile application.

### 4.2.2 Trick Recognition

3.2.2.1 Attributes:

3.2.2.1.1 Trick Database: Contains predefined movement signatures for classification.

3.2.2.1.2 Calculation Algorithm: Implements mathematical analysis of movement patterns.

3.2.2.2 Functions:

3.2.2.2.1 Identify trick types based on movement signatures.

3.2.2.2.2 Score execution quality and provide user feedback.

### 4.3 Performance Requirements

3.3.1 Data transmission latency: ≤ 50ms.

3.3.2 Sensor sampling rate: 200Hz.

3.3.3 Battery life: Minimum 5 hours of continuous operation in cold temperatures.

3.3.4 Data accuracy: 70%+ classification precision for trick recognition.

### 4.4 Design Constraints

3.4.1 Must be lightweight (<200g) and water-resistant.

3.4.2 Must not interfere with snowboard movement or rider flexibility.

### 4.5 Software System Attributes

3.5.1 Security: Encrypted Bluetooth data transmission.

3.5.2 Maintainability: Modular architecture for easy firmware updates.

3.5.3 Portability: Mobile application must support Android 10+ and iOS 14+.

7

### 4.6 Other Requirements

3.6.1 Compliance with CE, FCC, and RoHS regulatory standards.

3.6.2 Multi-user support for team-based analytics and sharing ride data.

## 5 Feature Summary & Development Status

The table below provides a consolidated overview of the key features defined in this Software Requirements Specification, along with their implementation status as of April 14, 2025. This summary serves to clarify the project’s scope
and prioritize future development efforts.
Feature | Description | Status (April 2025)
Sensor Data Collection | Real-time capture of acceleration, gyroscopic data, and GPS from wearable sensors. | Completed
Bluetooth Connectivity | Continuous BLE connection between ESP32-based wearable and mobile application. | Completed
Data Fusion & Processing | Combining multi-sensor data for accurate mo-tion tracking and terrain adaptation. | Completed
Mobile App UI | Interface for ride summaries, GPS mapping, scorecards, and performance feedback. | Completed
Ride History Log | Stores and displays past run metadata and analysis. | Planned
Performance Grading | Algorithm to evaluate ride metrics like air-time, carving angle, and trick smoothness. | Planned
Trick Recognition | Machine learning model to detect and classify tricks from motion patterns. | In Progress
3D Ride Visualization | Visual replay of ride data using onboard telemetry. | Planned
User Recommendations | Tailored tips and suggestions based on ride performance and rider profile. | Planned
Battery Optimization | Minimum 5 hours of operation with power-efficient sampling and wireless protocols. | Tested and Func-tional
Cross-Platform Support | Compatibility with Android 10+ and iOS 14+ via Flutter framework. | In Progress
Regulatory Compliance | Meets CE, FCC, RoHS standards for safety and electronic device regulations. | Planned

8

Removed or Deferred Requirements Table

The following table lists requirements that were planned in earlier stages but have either been deferred for future development or are still in progress as of
Version 1.4.
ID | Requirement Description | Reason for Removal / Delay | Status
R-1 | Performance Grading – Analyze ride metrics like airtime and carving an- gles | Planned for future development due to deadline/time constraints | [FUTURE]
R-2 | Ride Visualization – 3D replay of
ride data
Deferred to post-deadline cycle | [FUTURE]
R-3 | Mobile App Full Implementation –
Full UI & backend logic (select features only completed)

Remaining parts deferred for next version

[PARTIALLY COMPLETED / FUTURE]

R-4 User Recommendations – Tailored tips based on riding style and performance

Not implemented yet; part of planned user feedback system

[FUTURE]

R-5 Ride History Log – Storing and displaying past runs

Not implemented by April 2025 | [FUTURE]
R-6 | Regulatory Compliance – CE, FCC,
RoHS adherence

Pending hardware iteration for certification

[FUTURE]

R-7 Cross-Platform Support – Full compatibility with Android/iOS

In progress; limited support implemented

[IN PROGRESS]

Table 3: Table of Requirements Deferred or Removed from Initial Scope

This document will serve as the baseline for future iterations, ensuring alignment with user needs and technical feasibility. Planned features are outlined in the project roadmap and will be implemented in subsequent development cycles.

9

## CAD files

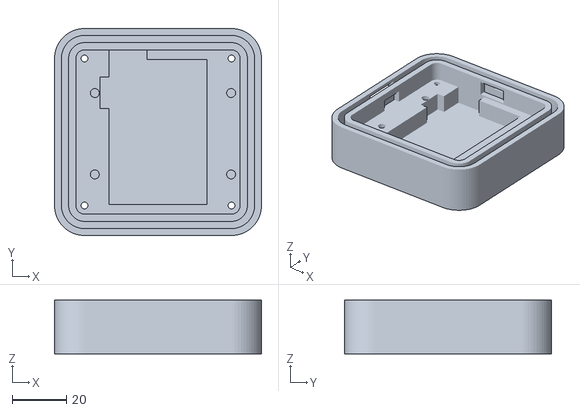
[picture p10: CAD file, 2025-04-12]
hardware/models/Main housing.stl
76.2 x 76.2 x 19.8

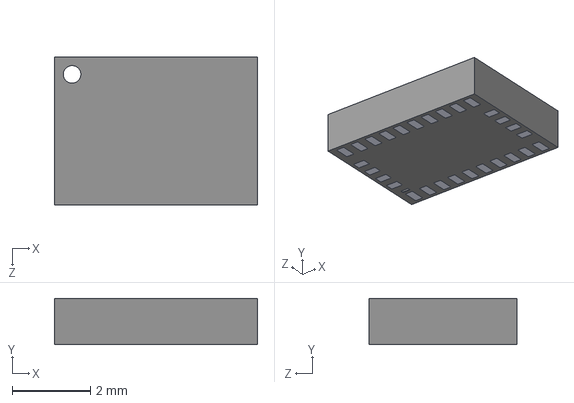
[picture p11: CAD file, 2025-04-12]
hardware/electrical/Snowboard-Recorder-PCB/models/BNO080.step
5.20 x 1.18 x 3.80 mm

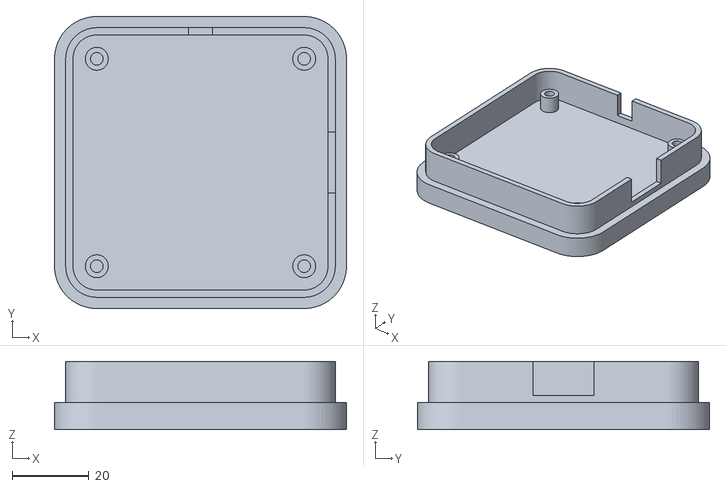
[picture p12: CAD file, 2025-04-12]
hardware/models/Cover.stl
76.2 x 76.2 x 17.8

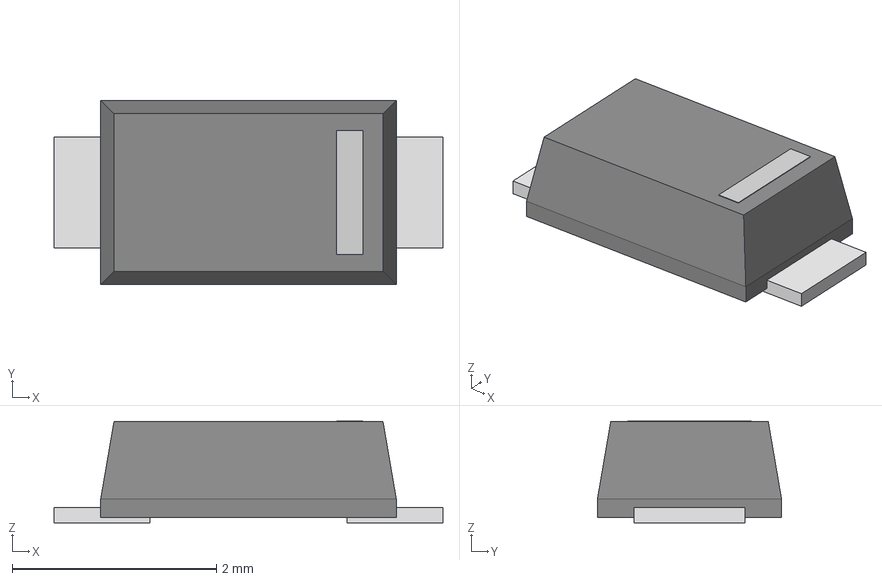
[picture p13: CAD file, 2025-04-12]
hardware/electrical/Snowboard-Recorder-PCB/models/SDO_SOD-123FL_498__OSI.step
3.81 x 1.80 x 0.997 mm

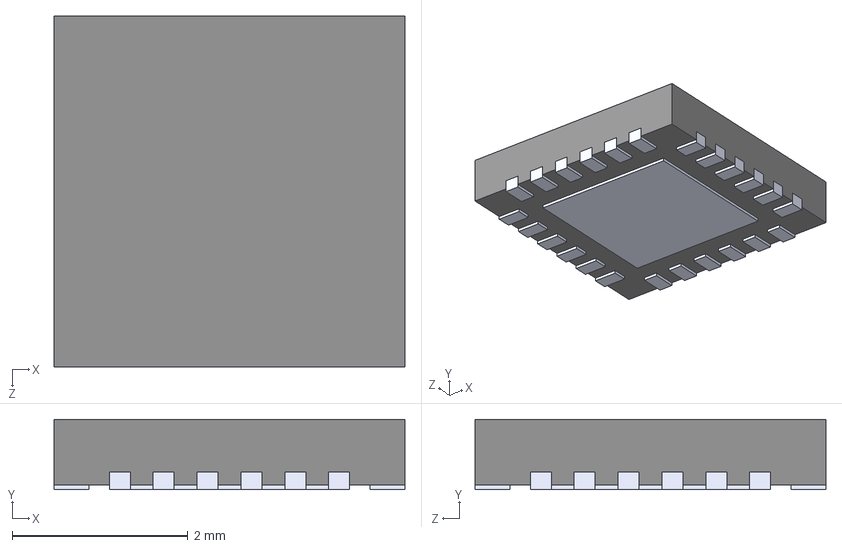
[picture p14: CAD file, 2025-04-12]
hardware/electrical/Snowboard-Recorder-PCB/models/CP2102N-A02-GQFN24.step
4.00 x 0.8 x 4.00 mm

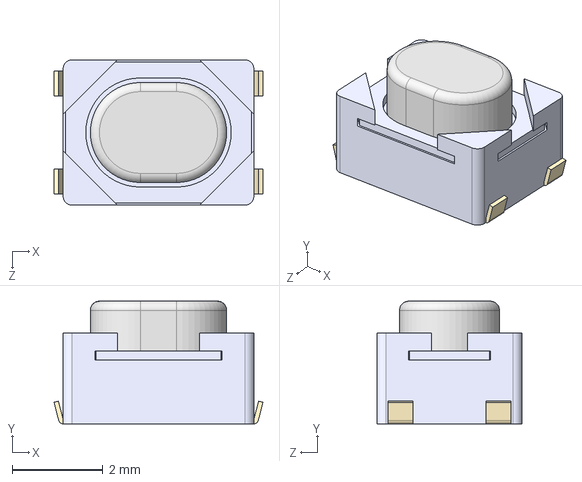
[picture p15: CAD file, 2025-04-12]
hardware/electrical/Snowboard-Recorder-PCB/models/PTS810_SJM_250_SMTR_LFS.step
4.60 x 2.70 x 3.20 mm

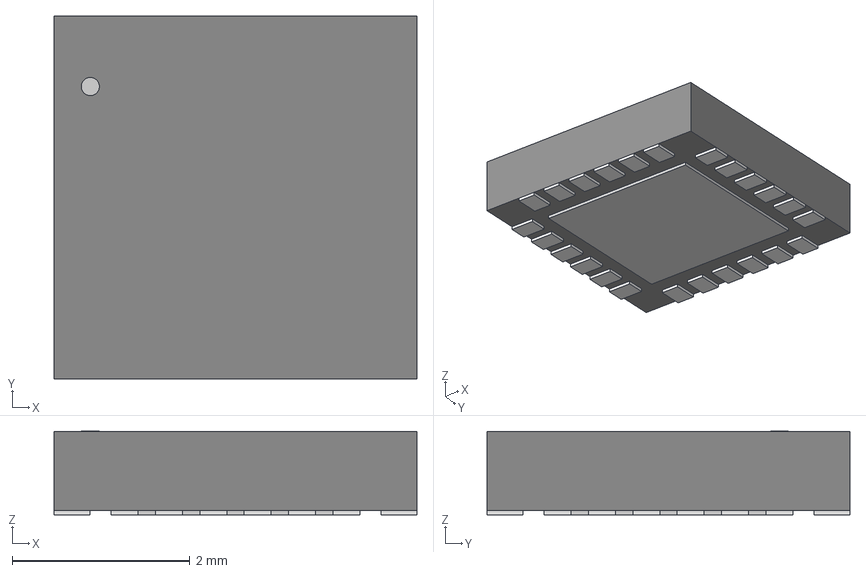
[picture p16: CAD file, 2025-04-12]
hardware/electrical/Snowboard-Recorder-PCB/models/MPU6050_QFN24_4X4X0P9-0P5_TDK.step
4.09 x 4.09 x 0.942 mm

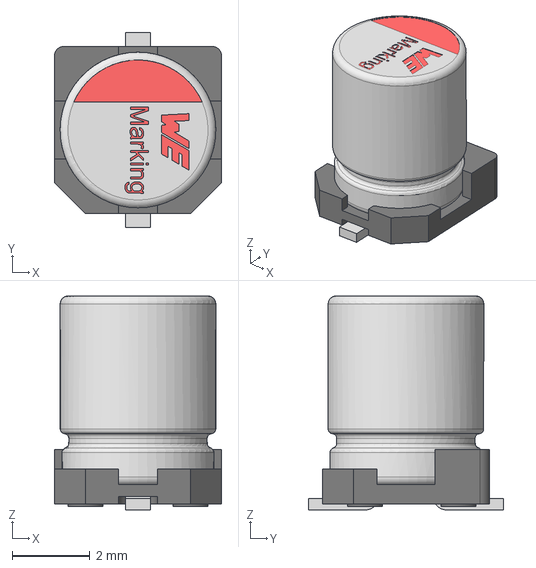
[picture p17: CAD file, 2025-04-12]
hardware/electrical/Snowboard-Recorder-PCB/models/WCAP-ASLL_4X5.5.step
4.30 x 5.00 x 5.50 mm
capicitor_4x5.5x1
Base_Φ4Capacitor

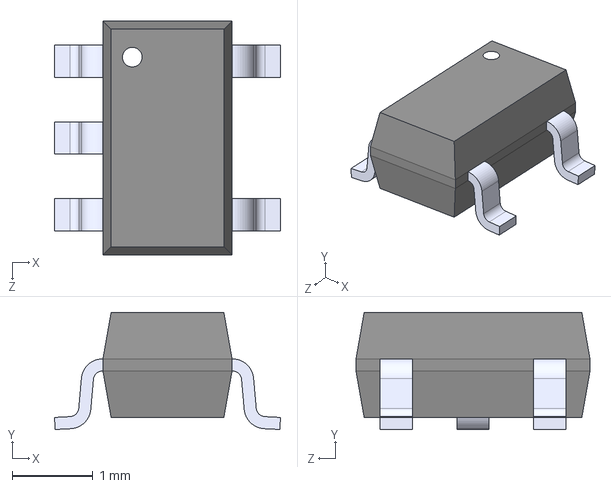
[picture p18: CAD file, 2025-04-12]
hardware/electrical/Snowboard-Recorder-PCB/models/SPX3819M5-L-3-3.step
2.80 x 1.45 x 2.90 mm

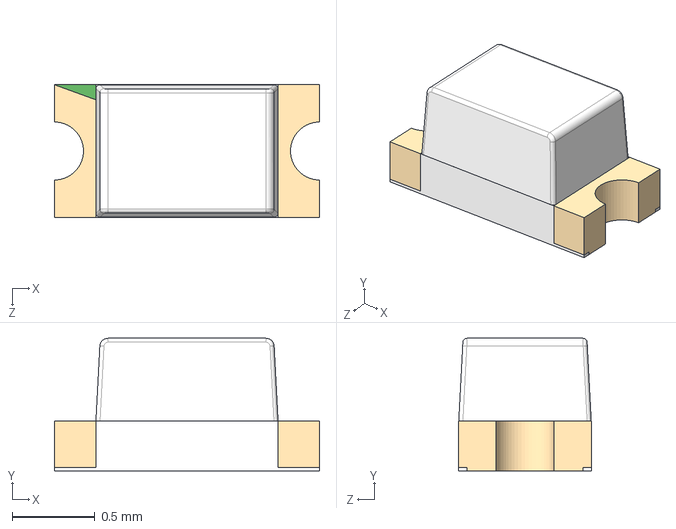
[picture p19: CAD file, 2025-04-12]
hardware/electrical/Snowboard-Recorder-PCB/models/WL-SMCW_0603.step
1.60 x 0.8 x 0.8 mm

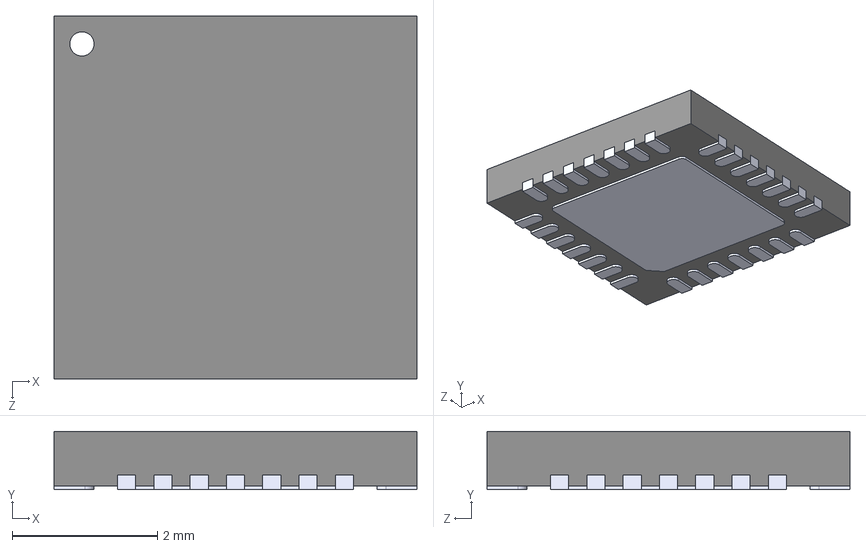
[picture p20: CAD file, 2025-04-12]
hardware/electrical/Snowboard-Recorder-PCB/models/CP2102N-A02-GQFN28R.step
5.00 x 0.8 x 5.00 mm

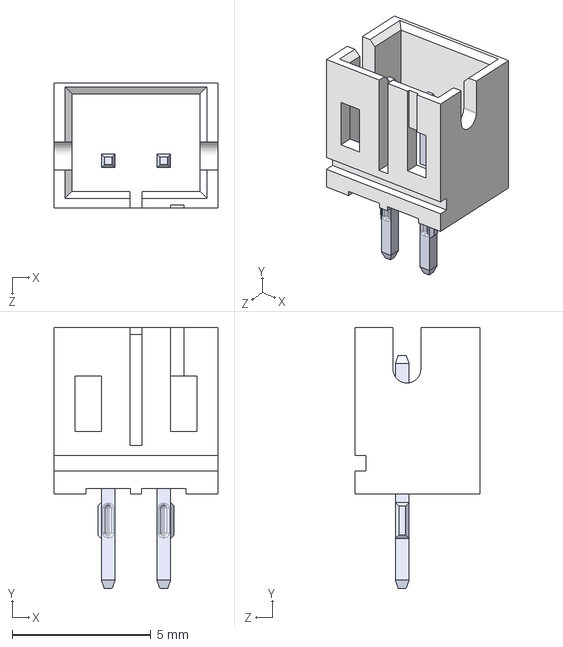
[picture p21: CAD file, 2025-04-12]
hardware/electrical/Snowboard-Recorder-PCB/models/B2B-PH-K-S.step
5.90 x 9.40 x 4.50 mm

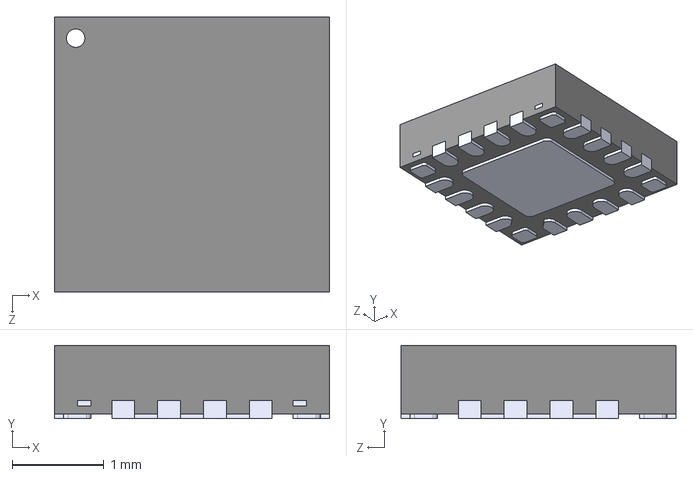
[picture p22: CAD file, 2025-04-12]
hardware/electrical/Snowboard-Recorder-PCB/models/CP2102N-A02-GQFN20R.step
3.00 x 0.8 x 3.00 mm

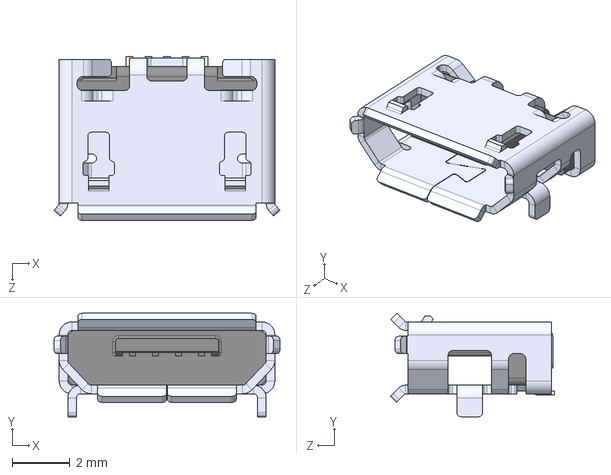
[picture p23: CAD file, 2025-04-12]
hardware/electrical/Snowboard-Recorder-PCB/models/10118193-0001LF.step
7.86 x 3.60 x 5.71 mm

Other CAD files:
hardware/electrical/Snowboard-Recorder-PCB/models/MCP73831T-2ACI_OT.step

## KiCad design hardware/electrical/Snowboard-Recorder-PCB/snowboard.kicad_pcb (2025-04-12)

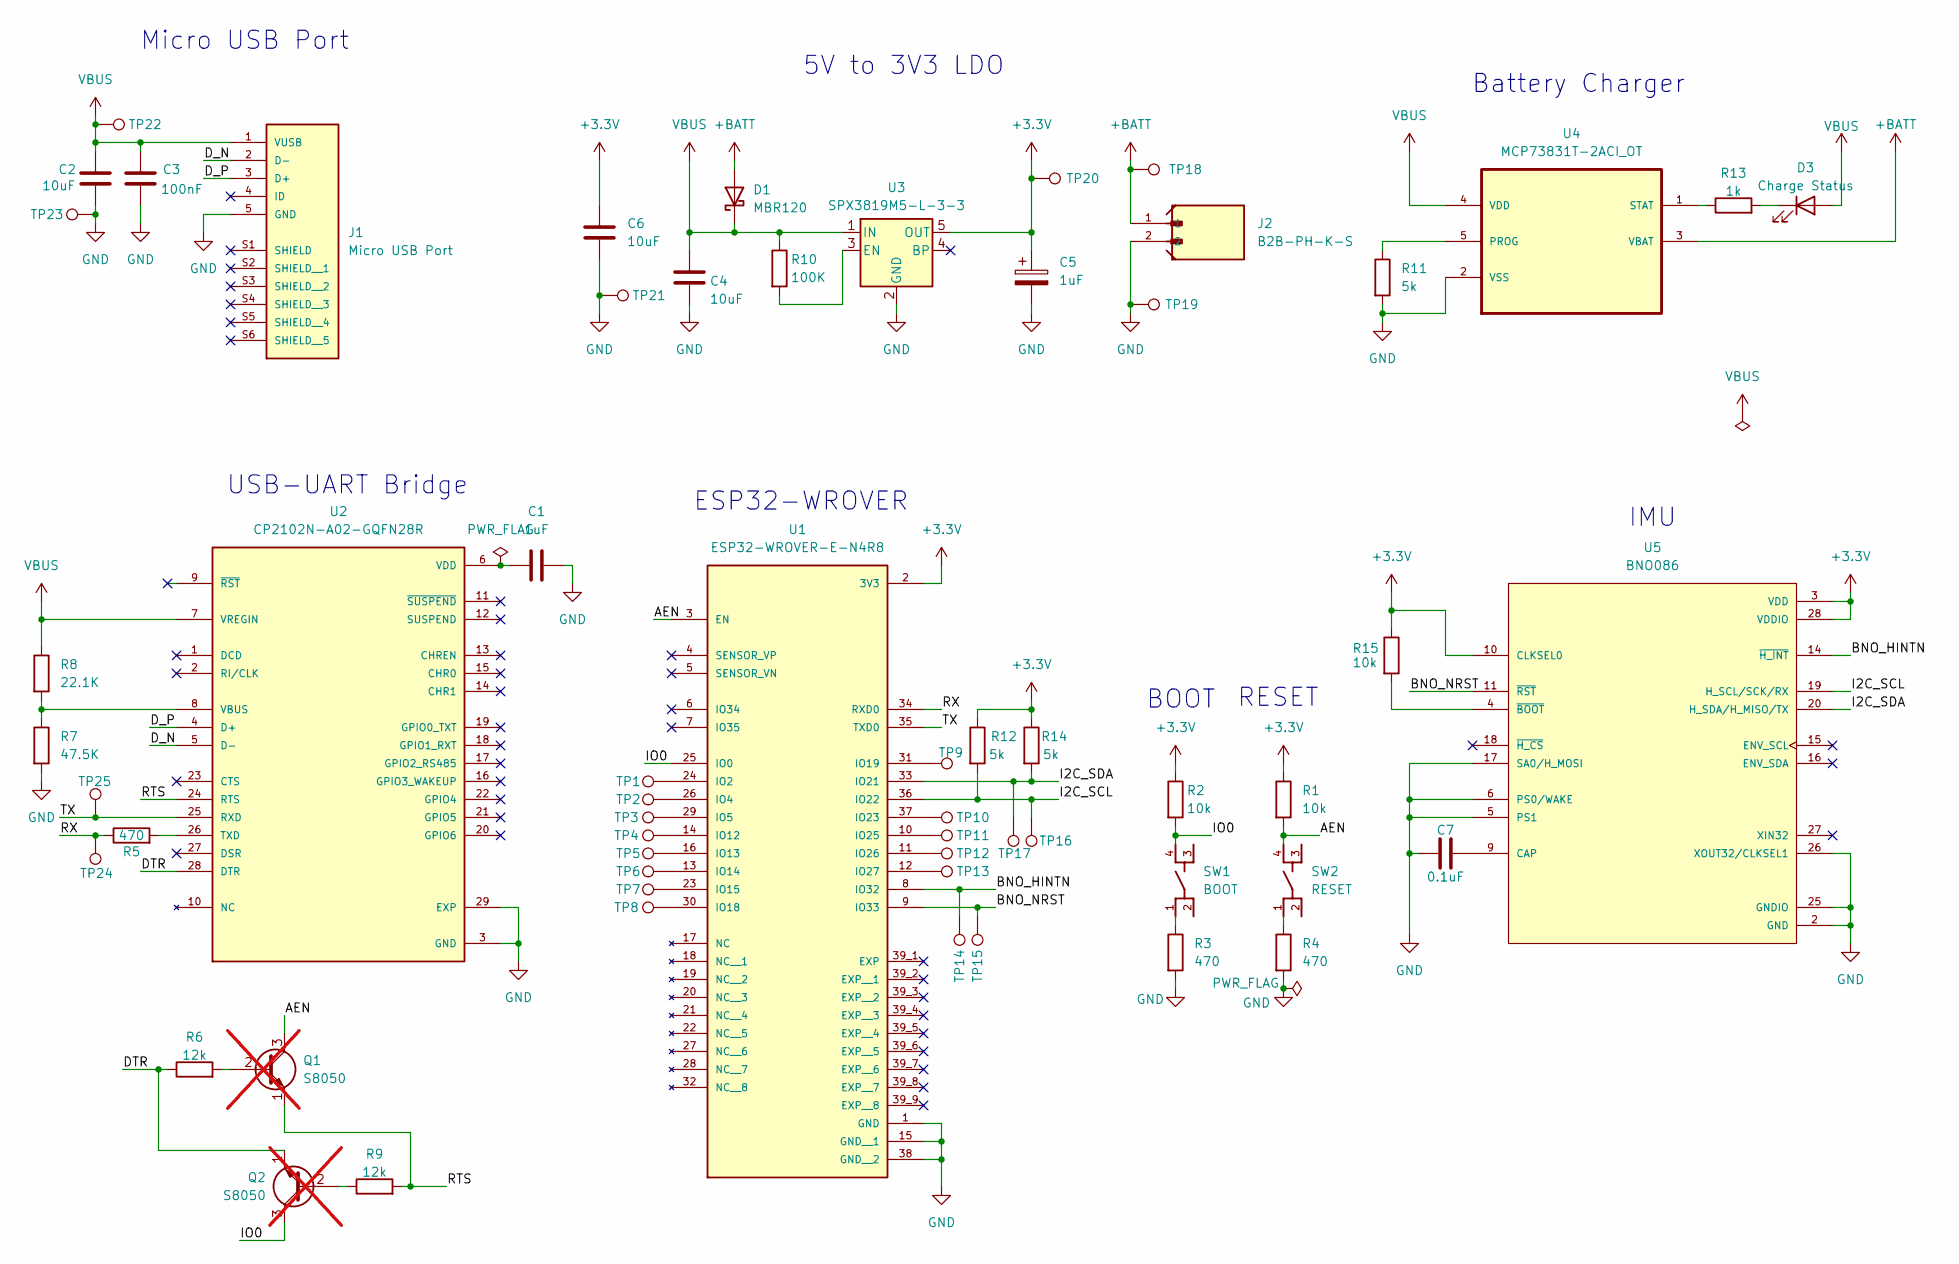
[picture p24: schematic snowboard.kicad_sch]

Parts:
C1, C5: 1uF
C2, C4, C6: 10uF
C3: 100nF
C7: 0.1uF
D1: MBR120
D3: Charge Status
J1: Micro USB Port; AMPHENOL_10118193-0001LF; PARTREV E
J2: B2B-PH-K-S; JST_B2B-PH-K-S
Q1, Q2: S8050; TO-92_Inline; not fitted
R1, R2, R15: 10k
R3, R4, R5: 470
R6, R9: 12k
R7: 47.5K
R8: 22.1K
R10: 100K
R11, R12, R14: 5k
R13: 1k
SW1: BOOT; SW_PTS810_SJM_250_SMTR_LFS
SW2: RESET; SW_PTS810_SJM_250_SMTR_LFS
TP1, TP2, TP3, TP4, TP5, TP6, TP7, TP8, TP9, TP10, TP11, TP12, TP13, TP14, TP15, TP16, TP17, TP18, TP19, TP20, TP21, TP22, TP23, TP24, TP25: TestPoint
U1: ESP32-WROVER-E-N4R8; XCVR_ESP32-WROVER-E-N4R8; PARTREV 1.6
U2: CP2102N-A02-GQFN28R; IC_CP2102N-A02-GQFN28R; PARTREV 1.5
U3: SPX3819M5-L-3-3; SOT-23-5
U4: MCP73831T-2ACI_OT; SOT95P280X145-5N; MPN MCP73831T-2ACI/OT
U5: BNO086; IC_BNO080; PARTREV 1.6

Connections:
+3.3V: C5.1, C6.1, R1.1, R2.1, R12.1, R14.1, R15.1, TP20.1, U1.2 (3V3), U3.5 (OUT), U5.3 (VDD), U5.10 (CLKSEL0), U5.28 (VDDIO)
+BATT: D1.2 (A), J2.1, TP18.1, U4.3 (VBAT)
/AEN: Q1.3 (C), R1.2, SW2.4, U1.3 (EN)
/BNO_HINTN: TP14.1, U1.8 (IO32), U5.14 (~H_INT)
/BNO_NRST: TP15.1, U1.9 (IO33), U5.11 (~RST)
/DTR: Q2.1 (E), R6.1, U2.28 (DTR)
/D_N: J1.2 (D-), U2.5 (D-)
/D_P: J1.3 (D+), U2.4 (D+)
/I2C_SCL: R12.2, TP16.1, U1.36 (IO22), U5.19 (H_SCL/SCK/RX)
/I2C_SDA: R14.2, TP17.1, U1.33 (IO21), U5.20 (H_SDA/H_MISO/TX)
/IO0: Q2.3 (C), R2.2, SW1.4, U1.25 (IO0)
/RTS: Q1.1 (E), R9.2, U2.24 (RTS)
/RX: R5.1, TP24.1, U1.34 (RXD0)
/TX: TP25.1, U1.35 (TXD0), U2.25 (RXD)
GND: C1.2, C2.2, C3.2, C4.2, C5.2, C6.2, C7.1, J1.5 (GND), J2.2, R3.2, R4.2, R7.2, R11.2, TP19.1, TP21.1, TP23.1, U1.1 (GND), U1.15 (GND__1), U1.38 (GND__2), U2.3 (GND), U2.29 (EXP), U3.2 (GND), U4.2 (VSS), U5.2 (GND), U5.5 (PS1), U5.6 (PS0/WAKE), U5.17 (SA0/H_MOSI), U5.25 (GNDIO), U5.26 (XOUT32/CLKSEL1)
unnamed: D3.1 (K), R13.2
unnamed: Q1.2 (B), R6.2
unnamed: Q2.2 (B), R9.1
unnamed: R3.1, SW1.1
unnamed: R4.1, SW2.1
unnamed: TP1.1, U1.24 (IO2)
unnamed: TP2.1, U1.26 (IO4)
unnamed: TP3.1, U1.29 (IO5)
unnamed: TP4.1, U1.14 (IO12)
unnamed: TP5.1, U1.16 (IO13)
unnamed: TP6.1, U1.13 (IO14)
unnamed: TP7.1, U1.23 (IO15)
unnamed: TP8.1, U1.30 (IO18)
unnamed: TP9.1, U1.31 (IO19)
unnamed: TP10.1, U1.37 (IO23)
unnamed: TP11.1, U1.10 (IO25)
unnamed: TP12.1, U1.11 (IO26)
unnamed: TP13.1, U1.12 (IO27)
unnamed: R5.2, U2.26 (TXD)
unnamed: R7.1, R8.2, U2.8 (VBUS)
unnamed: C1.1, U2.6 (VDD)
unnamed: R10.2, U3.3 (EN)
unnamed: R11.1, U4.5 (PROG)
unnamed: R13.1, U4.1 (STAT)
unnamed: C7.2, U5.9 (CAP)
unnamed: R15.2, U5.4 (~BOOT)
VBUS: C2.1, C3.1, C4.1, D1.1 (K), D3.2 (A), J1.1 (VUSB), R8.1, R10.1, TP22.1, U2.7 (VREGIN), U3.1 (IN), U4.4 (VDD)

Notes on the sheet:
USB-UART Bridge
IMU
Battery Charger
Micro USB Port
ESP32-WROVER
RESET
5V to 3V3 LDO
BOOT

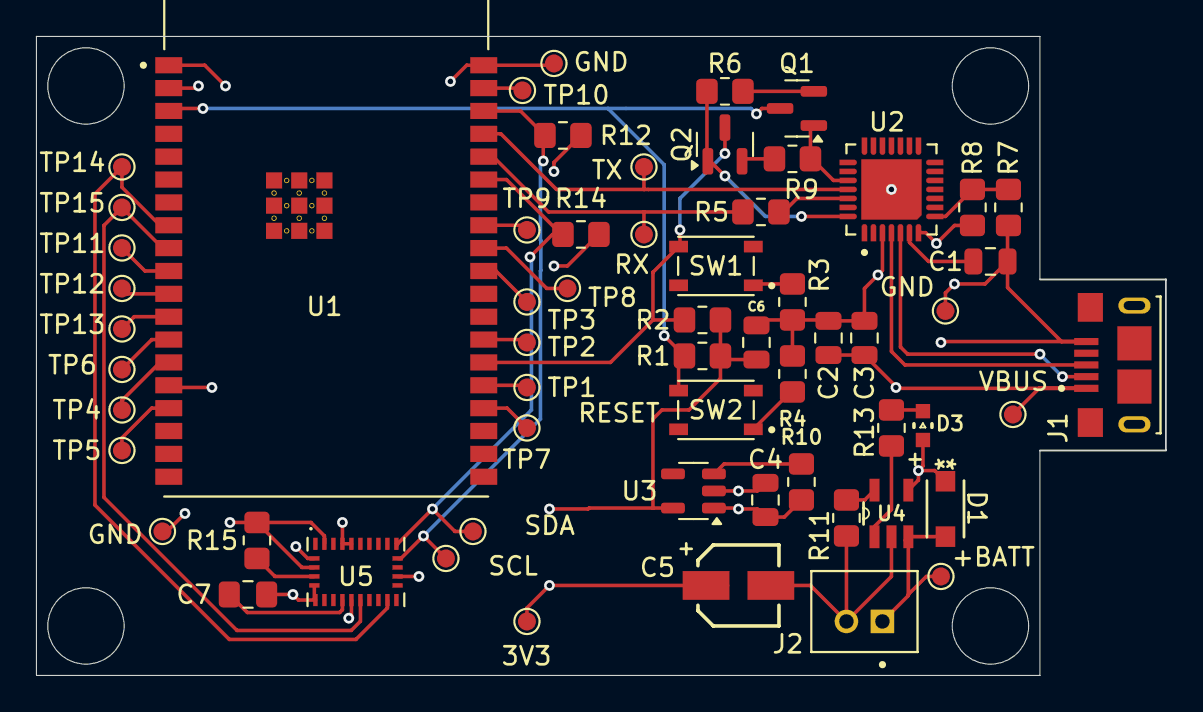
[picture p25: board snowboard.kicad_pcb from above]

Board: 4 copper layers, 62.8 x 35.5 mm, 60 parts (0 on the bottom side), 42 nets.

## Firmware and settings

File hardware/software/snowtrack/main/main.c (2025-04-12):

/*
 * SPDX-FileCopyrightText: 2021-2024 Espressif Systems (Shanghai) CO LTD
 *
 * SPDX-License-Identifier: Unlicense OR CC0-1.0
 */

#include <stdint.h>
#include <string.h>
#include <stdbool.h>
#include <stdio.h>
#include <inttypes.h>

#include "nvs.h"
#include "nvs_flash.h"
#include "freertos/FreeRTOS.h"
#include "freertos/task.h"
#include "esp_log.h"
#include "esp_bt.h"
#include "esp_bt_main.h"
#include "esp_gap_bt_api.h"
#include "esp_bt_device.h"
#include "esp_spp_api.h"
#include "sh2.h"
#include "bno08x.h"
#include "spp_server.h"

#include "time.h"
#include "sys/time.h"

#define DEG_TO_RAD 0.017453292519943295769236907684886
#define RAD_TO_DEG 57.295779513082320876798154814105

// #define SPP_TAG 
#define SPP_SERVER_NAME "SPP_SERVER"
#define SPP_SHOW_DATA 0
#define SPP_SHOW_SPEED 1
#define SPP_SHOW_MODE SPP_SHOW_DATA    /*Choose show mode: show data or speed*/

static const char *TAG = "main";

static struct timeval time_new, time_old;
static long data_num = 0;

static uint32_t recent_handle = 0;

void app_main(void)
{
    esp_log_level_set(TAG, ESP_LOG_DEBUG);

    char bda_str[18] = {0};
    esp_err_t ret = nvs_flash_init();
    if (ret == ESP_ERR_NVS_NO_FREE_PAGES || ret == ESP_ERR_NVS_NEW_VERSION_FOUND) {
        ESP_ERROR_CHECK(nvs_flash_erase());
        ret = nvs_flash_init();
    }

    ESP_ERROR_CHECK(ret);

    TaskHandle_t imu_task;
    BaseType_t rtos_ret = xTaskCreate(
        bno_task, 
        "IMU Recorder", 
        40000 / sizeof(configSTACK_DEPTH_TYPE), 
        NULL, 
        configMAX_PRIORITIES - 2, 
        &imu_task
    );

    TaskHandle_t bt_server_task;
    rtos_ret = xTaskCreate(
        server_task,
        "Bluetooth Server",
        30000 / sizeof(configSTACK_DEPTH_TYPE), 
        NULL, 
        configMAX_PRIORITIES / 2, 
        &bt_server_task
    );

    // quat_t result;
    // QueueHandle_t imu_result_queue = bno_get_result_queue();
    // ESP_LOGD(TAG, "Starting main loop");
    // while (1) {
    //     if ((rtos_ret = xQueueReceive(imu_result_queue, &result, pdMS_TO_TICKS(1000))) != pdPASS) {
    //         ESP_LOGW(TAG, "No IMU results");
    //     } else {
    //         ESP_LOGD(TAG, "IMU result recieved: z = %f", result.z);
    //     }
    // }

    // if (create_ret == pdFAIL) {

    // } else if (create_ret == pdPASS) {

    // }
}

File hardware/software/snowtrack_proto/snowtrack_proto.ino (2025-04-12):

#include <Arduino.h>
#include <Adafruit_BNO08x.h>

#include "BluetoothSerial.h"

#if !defined(CONFIG_BT_ENABLED) || !defined(CONFIG_BLUEDROID_ENABLED)
#error Bluetooth is not enabled! Please run `make menuconfig` to and enable it
#endif

#define BNO08X_CS 10
#define BNO08X_INT 9
#define BNO08X_RESET -1

BluetoothSerial SerialBT;
Adafruit_BNO08x bno08x(BNO08X_RESET);
sh2_SensorValue_t sensorValue;
sh2_SensorId_t reportType = SH2_ROTATION_VECTOR;
sh2_RotationVectorWAcc_t* meas;
long reportIntervalUs = 5000;

// Set bno report type and interval
void setReports(sh2_SensorId_t reportType, long report_interval) {
  Serial.println("Setting desired reports");
  if (!bno08x.enableReport(reportType, report_interval)) {
    Serial.println("Could not enable stabilized remote vector");
  }
}

void setup(void) {
  Serial.begin(115200);

  while (!Serial) delay(10);
  // Start SnowTrack bluetooth server
  SerialBT.begin("SnowTrack");

  Serial.println("Adafruit BNO08x test!");

  // Initialize BNO086 on I2C bus
  if (!bno08x.begin_I2C()) {
    Serial.println("Failed to find BNO08x chip");
    while (1) { delay(10); }
  }
  Serial.println("BNO08x Found!");

  setReports(reportType, reportIntervalUs);

  Serial.println("Reading events");
  delay(100);
}

void loop() {
  if (bno08x.wasReset()) {
    Serial.print("sensor was reset ");
    setReports(reportType, reportIntervalUs);
  }

  // Read sensor event and send to bluetooth clients
  if (bno08x.getSensorEvent(&sensorValue)) {
    if (sensorValue.sensorId == SH2_ROTATION_VECTOR) {
      meas = &sensorValue.un.rotationVector;
      Serial.printf("%fw %fx %fy %fz\n", meas->real, meas->i, meas->j, meas->k);
      SerialBT.printf("%f %f %f %f\n", meas->real, meas->i, meas->j, meas->k);
    }
  }
}

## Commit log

2025-04-12 Add hardware sources
    [10118193-0001LF.step, B2B-PH-K-S.step, BNO080.step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]
2025-04-14 Add runs and edited algorithms
    [run11.csv, run7.csv, run8.csv]
